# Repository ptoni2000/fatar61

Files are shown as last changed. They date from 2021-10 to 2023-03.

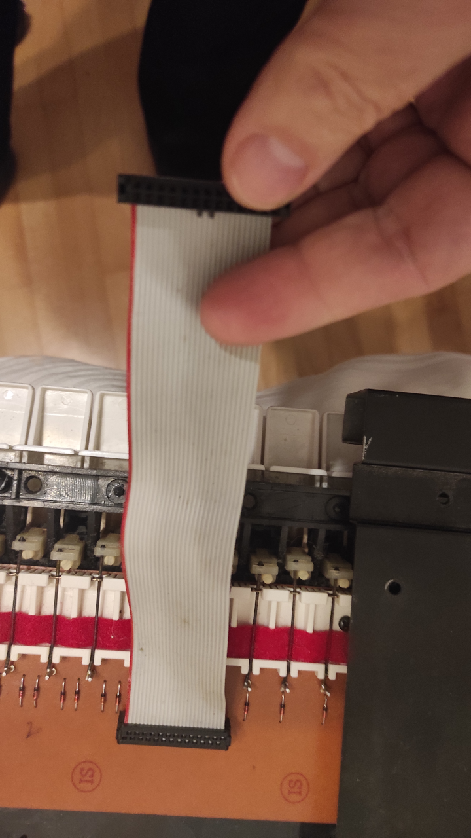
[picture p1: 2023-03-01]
Documentation/cable.png

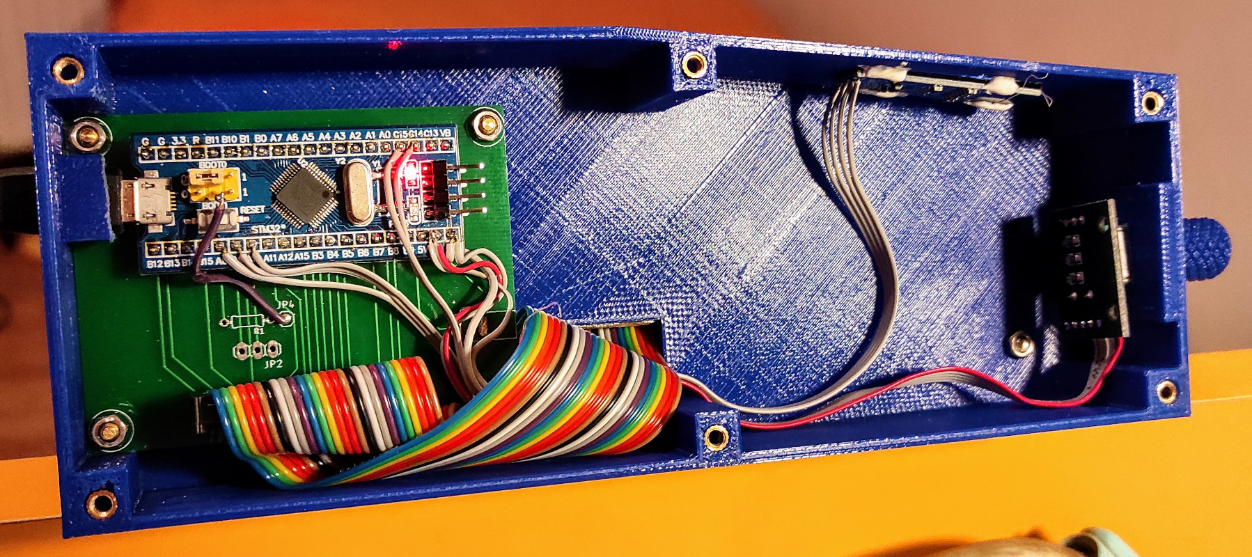
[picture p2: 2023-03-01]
Documentation/box.png

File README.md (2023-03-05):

# fatar61
Midi for Fatar 61 keys keyboard

This is a midi with blue pill board

The Midi interface is USB

Eagle directory contain schematic and pcb
Documentation contain some photos and videos of the board, box and cable

The keyboard is working wery well when connected to minisynt32: https://github.com/grantek/minisynth32

# NOTE: the actual firmware is on repository fatar61_tinyUSB !!!

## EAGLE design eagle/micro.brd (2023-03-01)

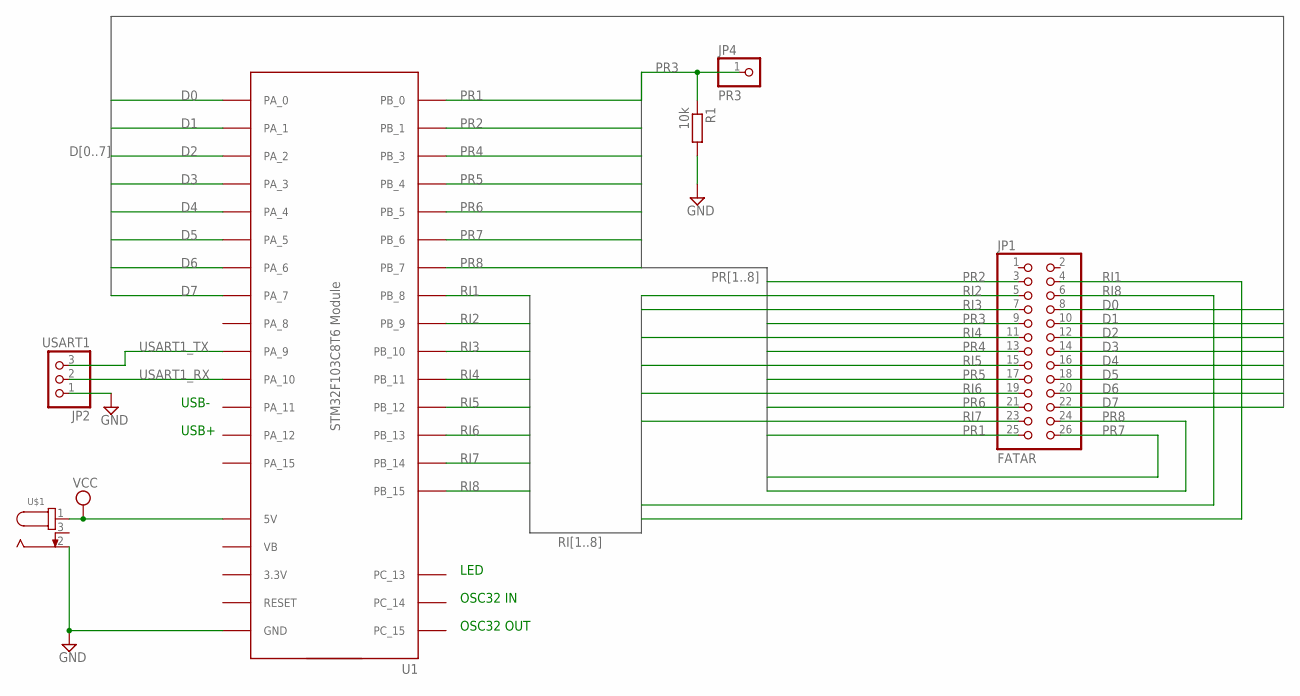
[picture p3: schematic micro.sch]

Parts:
JP1: FATAR; 2X13
JP2: USART1; 1X03
JP4: PR3; 1X01
R1: 10k; 0204/7
U1: STM32F103C8T6-MODULE
U$1: 694103303002

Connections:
D0: JP1.8, U1.PA_0
D1: JP1.10, U1.PA_1
D2: JP1.12, U1.PA_2
D3: JP1.14, U1.PA_3
D4: JP1.16, U1.PA_4
D5: JP1.18, U1.PA_5
D6: JP1.20, U1.PA_6
D7: JP1.22, U1.PA_7
GND: JP2.1, R1.2, U1.GND@1 (GND), U1.GND@2 (GND), U1.GND@3 (GND), U$1.2
PR1: JP1.25, U1.PB_0
PR2: JP1.3, U1.PB_1
PR3: JP1.9, JP4.1, R1.1
PR4: JP1.13, U1.PB_3
PR5: JP1.17, U1.PB_4
PR6: JP1.21, U1.PB_5
PR7: JP1.26, U1.PB_6
PR8: JP1.24, U1.PB_7
RI1: JP1.4, U1.PB_8
RI2: JP1.5, U1.PB_9
RI3: JP1.7, U1.PB_10
RI4: JP1.11, U1.PB_11
RI5: JP1.15, U1.PB_12
RI6: JP1.19, U1.PB_13
RI7: JP1.23, U1.PB_14
RI8: JP1.6, U1.PB_15
USART1_RX: JP2.2, U1.PA_10
USART1_TX: JP2.3, U1.PA_9
VCC: U1.5V, U$1.1

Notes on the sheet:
LED
OSC32 IN
OSC32 OUT
USB-
USB+

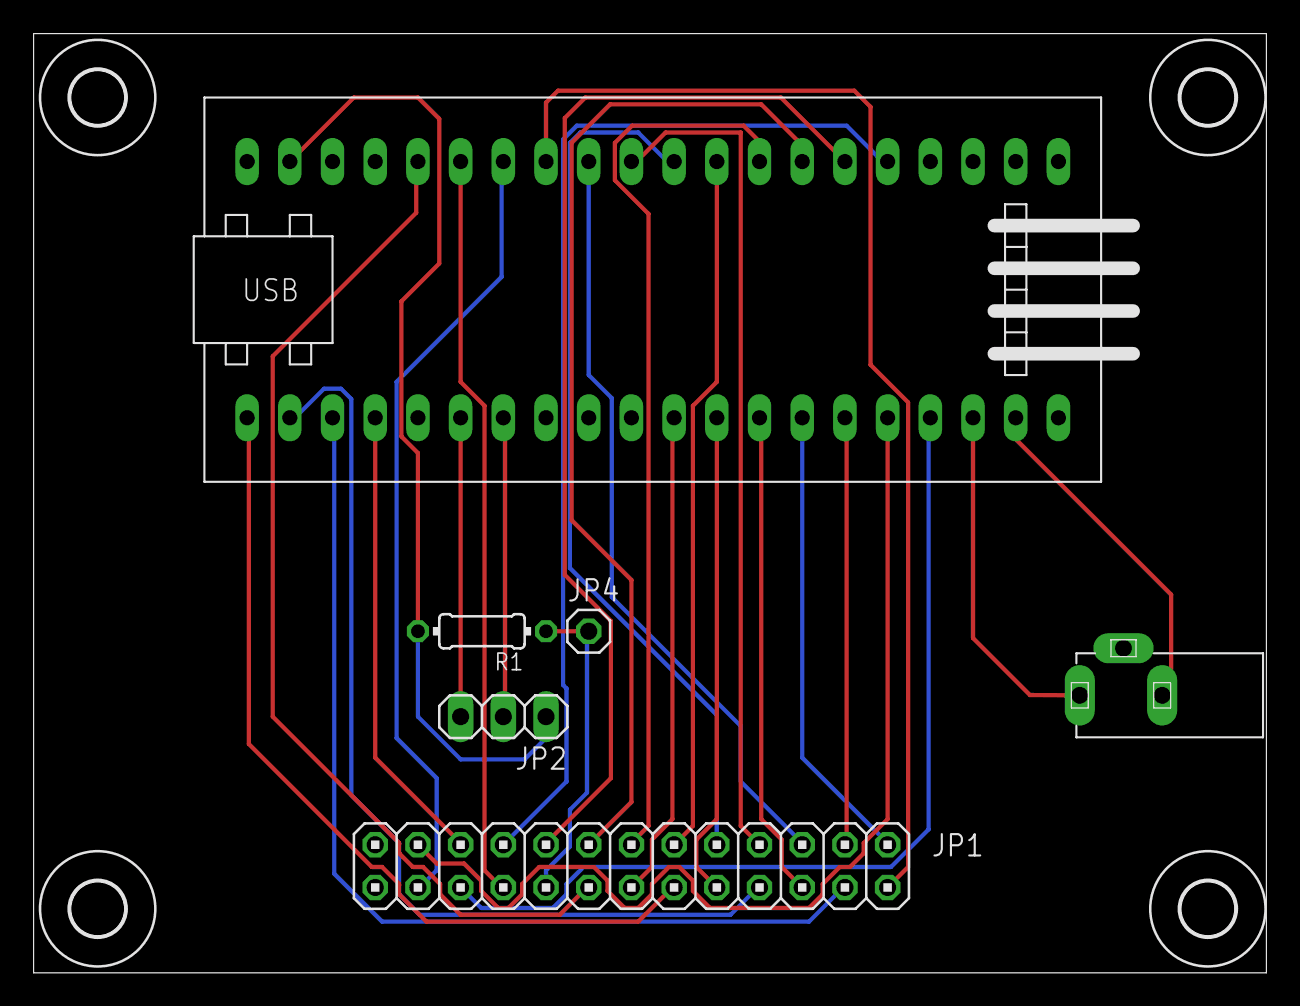
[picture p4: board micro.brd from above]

Board: 2 copper layers, 73.3 x 55.9 mm, 10 parts (0 on the bottom side), 28 nets.

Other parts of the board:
U$2, U$3, U$4, U$5: 3,2

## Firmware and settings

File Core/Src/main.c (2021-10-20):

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
/* Includes ------------------------------------------------------------------*/
#include "main.h"
#include "usb_device.h"

/* USER CODE BEGIN Includes */
#include "startup.h"
#include "usb_device.h"
#include "usbd_midi_if.h"
/* USER CODE END Includes */

TIM_HandleTypeDef htim1;
TIM_HandleTypeDef htim2;

void SystemClock_Config(void);
static void MX_GPIO_Init(void);
static void MX_TIM1_Init(void);
static void MX_TIM2_Init(void);
/* USER CODE BEGIN 0 */
//#ifdef __GNUC__
//#define PUTCHAR_PROTOTYPE int __io_putchar(int ch)
//#else
//#define PUTCHAR_PROTOTYPE int fputc(int ch, FILE *f)
//#endif /* __GNUC__ */
//
///**
//  * @brief  Retargets the C library printf function to the USART.
//  * @param  None
//  * @retval None
//  */
//PUTCHAR_PROTOTYPE
//{
//  HAL_UART_Transmit(&huart1, (uint8_t *)&ch, 1, 100);
//  return ch;
//}

/* USER CODE END 0 */

/**
  * @brief  The application entry point.
  * @retval int
  */
int main(void)
{
  /* MCU Configuration--------------------------------------------------------*/

  /* Reset of all peripherals, Initializes the Flash interface and the Systick. */
  HAL_Init();

  /* Configure the system clock */
  SystemClock_Config();

  /* Initialize all configured peripherals */
  MX_GPIO_Init();
  MX_TIM1_Init();
  MX_TIM2_Init();
  MX_USB_DEVICE_Init();
  /* Infinite loop */
  /* USER CODE BEGIN WHILE */
  initialize();
  while (1)
  {
	  loop();
    /* USER CODE END WHILE */

    /* USER CODE BEGIN 3 */
  }
  /* USER CODE END 3 */
}

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


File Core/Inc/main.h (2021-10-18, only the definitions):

#define LED_Pin GPIO_PIN_13
#define LED_GPIO_Port GPIOC
#define D0_Pin GPIO_PIN_0
#define D0_GPIO_Port GPIOA
#define D1_Pin GPIO_PIN_1
#define D1_GPIO_Port GPIOA
#define D2_Pin GPIO_PIN_2
#define D2_GPIO_Port GPIOA
#define D3_Pin GPIO_PIN_3
#define D3_GPIO_Port GPIOA
#define D4_Pin GPIO_PIN_4
#define D4_GPIO_Port GPIOA
#define D5_Pin GPIO_PIN_5
#define D5_GPIO_Port GPIOA
#define D6_Pin GPIO_PIN_6
#define D6_GPIO_Port GPIOA
#define D7_Pin GPIO_PIN_7
#define D7_GPIO_Port GPIOA
#define PR1_Pin GPIO_PIN_0
#define PR1_GPIO_Port GPIOB
#define PR2_Pin GPIO_PIN_1
#define PR2_GPIO_Port GPIOB
#define PR3_Pin GPIO_PIN_2
#define PR3_GPIO_Port GPIOB
#define RI3_Pin GPIO_PIN_10
#define RI3_GPIO_Port GPIOB
#define RI4_Pin GPIO_PIN_11
#define RI4_GPIO_Port GPIOB
#define RI5_Pin GPIO_PIN_12
#define RI5_GPIO_Port GPIOB
#define RI6_Pin GPIO_PIN_13
#define RI6_GPIO_Port GPIOB
#define RI7_Pin GPIO_PIN_14
#define RI7_GPIO_Port GPIOB
#define RI8_Pin GPIO_PIN_15
#define RI8_GPIO_Port GPIOB
#define PR4_Pin GPIO_PIN_3
#define PR4_GPIO_Port GPIOB
#define PR5_Pin GPIO_PIN_4
#define PR5_GPIO_Port GPIOB
#define PR6_Pin GPIO_PIN_5
#define PR6_GPIO_Port GPIOB
#define PR7_Pin GPIO_PIN_6
#define PR7_GPIO_Port GPIOB
#define PR8_Pin GPIO_PIN_7
#define PR8_GPIO_Port GPIOB
#define RI1_Pin GPIO_PIN_8
#define RI1_GPIO_Port GPIOB
#define RI2_Pin GPIO_PIN_9
#define RI2_GPIO_Port GPIOB

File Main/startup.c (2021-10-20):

#include "startup.h"
#include <stdio.h>
#include <string.h>
#include <stdint.h>
#include "main.h"
#include "stm32f1xx_hal_tim.h"
#include "usbd_midi_if.h"

// Possible key states
typedef enum {
  KEY_IS_UP,
  KEY_IS_DOWN,
  KEY_IS_GOING_UP,    // We increment the timer in this state
  KEY_IS_GOING_DOWN,  // We increment the timer in this state
} state_t;

// Possible events
typedef enum {
  KEY_PRESSED,    // Key is pressed
  KEY_DOWN,       // Key reached bottom
  KEY_RELEASED,   // Key was released
  KEY_UP,         // Key reached top
} event_t;

typedef struct {
  char			midi_note	:8;
  state_t       state		:4; // Bit fields
  unsigned int  t    		:7; // Lines up nicely to 16bits, t overflows at 4096
} midikey_t;

typedef struct {
  uint8_t top;
  uint8_t bottom;
} bank_t;
#define NUM_KEYS 61

midikey_t keys[NUM_KEYS];

#define NUM_BANKS 8

// For scanning banks
bank_t banks[NUM_BANKS];
bank_t prev_banks[NUM_BANKS];
uint8_t program = 0;

void initialize()
{
	printf("%s\n", __func__);

	// Init keys
	for ( int key = 0; key < NUM_KEYS; key++) {
		keys[key].midi_note = 24 + key;
		keys[key].t = 0;
	}

	for(int i = 0; i< NUM_BANKS; i++) {
		banks[i].top = 0;
		banks[i].bottom = 1;
	}
	memcpy(prev_banks, banks, sizeof(prev_banks));

//	HAL_TIM_Base_Start(&htim1);
	HAL_TIM_Encoder_Start(&htim1, TIM_CHANNEL_ALL);
	HAL_TIM_Base_Start_IT(&htim2);
	HAL_GPIO_WritePin(LED_GPIO_Port, LED_Pin, GPIO_PIN_RESET);

}

void trigger(midikey_t *key, event_t event) {
	if(event == KEY_PRESSED) {
		key->state = KEY_IS_GOING_DOWN;
		HAL_GPIO_WritePin(LED_GPIO_Port, LED_Pin, GPIO_PIN_RESET);
		printf("GOING DOWN %d\n", key->midi_note);

	} else if (event == KEY_DOWN) {
		if(key->state == KEY_IS_GOING_DOWN) {
			key->state = KEY_IS_DOWN;
			HAL_GPIO_WritePin(LED_GPIO_Port, LED_Pin, GPIO_PIN_RESET);
			// note pressed
			MIDI_note_on(1, key->midi_note, 127- key->t);
			printf("DN %d %d\n", key->midi_note, 127- key->t);
			key->t = 0;
		}
	} else if (event == KEY_RELEASED) {
		key->state = KEY_IS_GOING_UP;
		HAL_GPIO_WritePin(LED_GPIO_Port, LED_Pin, GPIO_PIN_RESET);
		printf("GOING UP %d\n", key->midi_note);

	} else if ( event == KEY_UP) {
		if(key->state == KEY_IS_GOING_UP) {
			key->state = KEY_IS_UP;
			HAL_GPIO_WritePin(LED_GPIO_Port, LED_Pin, GPIO_PIN_SET);
			// note released
			MIDI_note_off(1, key->midi_note, 127- key->t);
			printf("UP %d %d\n", key->midi_note, 127- key->t);
			key->t = 0;
		}
	}
}

void increment() {
	// Advance timers
	for(int key = 0; key < NUM_KEYS; key++) {
		state_t state = keys[key].state;
		if(state == KEY_IS_GOING_UP || state == KEY_IS_GOING_DOWN) {
			if(keys[key].t < 126) keys[key].t++;
		}
	}
}

//void delay_us (uint16_t us)
//{
//	__HAL_TIM_SET_COUNTER(&htim1,0);  // set the counter value a 0
//	while (__HAL_TIM_GET_COUNTER(&htim1) < us);  // wait for the counter to reach the us input in the parameter
//}

void delay_us(uint32_t delay_us)
{
  volatile unsigned int num;
  volatile unsigned int t;


  for (num = 0; num < delay_us; num++)
  {
    t = 11;
    while (t != 0)
    {
      t--;
    }
  }
}

uint32_t deb[NUM_BANKS];
void scan(void) {
	uint8_t count[16];
	uint32_t val[3];
	int i;

	// Scan and store
	for(int bank = 0; bank < NUM_BANKS; bank++) {
		prev_banks[bank] = banks[bank]; // Store previous state so we can look for changes

		GPIOA->ODR |= (1<<bank)&0xff; // Selects bottom row
		delay_us(10); // wait voltage stabilize
		for (i=0; i<3; i++) {
			val[i] = GPIOB->IDR;
			delay_us(10); // wait voltage stabilize
		}

		for (i=0; i<16; i++) {
			count[i] = 0;
			if(val[0] & 1<<i) ++count[i];
			if(val[1] & 1<<i) ++count[i];
			if(val[2] & 1<<i) ++count[i];
			if(count[i] == 3) {
				deb[bank] |= (1<<i);
			}
			else {
				deb[bank] &= ~(1<<i);
			}
		}

		banks[bank].bottom = deb[bank] & 0xff;
		banks[bank].top    = deb[bank] >> 8;
		GPIOA->ODR &=  ~((1<<bank)&0xff); // Selects bottom row
	}

	// Process
	for(int bank = 0; bank < NUM_BANKS; bank++) {

		uint8_t diff;

		// Check top switches and fire events
		diff = banks[bank].top ^ prev_banks[bank].top;
		if(diff) {
			for(int key = 0; key < 8; key++) {
				if(diff & (1<<key)) {
					event_t event = banks[bank].top & (1<<key) ? KEY_UP : KEY_PRESSED;
					trigger(&keys[bank + 8 * key], event);
				}
			}
		}

		// Check bottom switches and fire events
		diff = banks[bank].bottom ^ prev_banks[bank].bottom;
		if(diff) {
			for(int key = 0; key < 8; key++) {
				if(diff & (1<<key)) {
					event_t event = banks[bank].bottom & (1<<key) ? KEY_DOWN : KEY_RELEASED;
					trigger(&keys[bank + 8 * key], event);
				}
			}
		}

	}

}

void encoder(void)
{
	uint32_t encoder_val;
	static uint32_t old_encoder = 0;
	static uint32_t now = 0;
	static int update = 0;

	encoder_val = (TIM1->CNT)>>2;

	if(old_encoder != encoder_val) {
		now = HAL_GetTick();
		update = 1;
		old_encoder = encoder_val;
	}

	if(HAL_GetTick() - now > 200 && update) {
		program = encoder_val % 127;
		MIDI_pc_update(1, program);
		update = 0;
	}

}

void HAL_TIM_PeriodElapsedCallback(TIM_HandleTypeDef* htim) {

	if (htim->Instance == TIM2) {
		//scan();
		increment();
	}
}

void loop()
{
	scan();
	encoder();
}

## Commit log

2021-08-18 Add timer1 for delay_us
2021-08-18 Add retarget printf on USART1
2021-10-18 Chiamata dal timer2 ogni millisecondo
2021-10-18 USB device hard reset
    [main.c]
2021-10-19 Scan in loop, non in timer
2021-10-19 USB_DEVICE da stm32f4-midi-brain
2021-10-19 Maste hard reset USB
    [main.c]
2021-10-20 encoder collegato su piedini uart.
    [fatar61 Debug.cfg]
2023-03-01 Added documentation, schematic and pictures.
    [micro.brd, micro.sch]

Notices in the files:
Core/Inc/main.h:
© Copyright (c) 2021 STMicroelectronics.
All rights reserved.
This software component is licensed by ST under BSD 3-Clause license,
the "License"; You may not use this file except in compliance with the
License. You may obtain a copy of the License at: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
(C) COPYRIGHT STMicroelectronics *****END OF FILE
